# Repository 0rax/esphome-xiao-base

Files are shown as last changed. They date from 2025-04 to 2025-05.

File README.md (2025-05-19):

# XIAO Base for ESPHome





The XIAO Base for ESPHome is a custom PCB designed to be used with the [ESPHome](https://esphome.io/) firmware as a base for creating new sensors.

It was made as a carrier board for the XIAO series of microcontrollers with an OLED display and three switches while providing an easy-to-access header on the back for standard communication protocols (I²C, UART and SPI).

A cutout has also been left for the underside of the XIAO to allow access to the battery pads available on the underside of some modules (such as the [XIAO ESP32C6]).

## PCB

| Render | Front | Back |
| :---: | :---: | :---: |
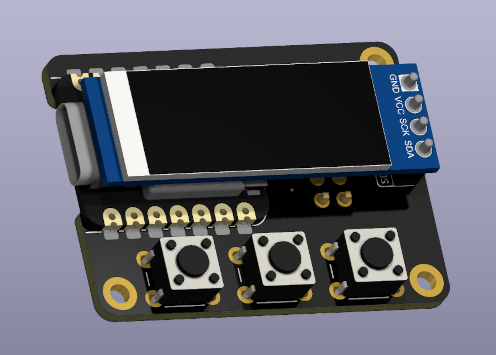
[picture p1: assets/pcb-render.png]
PCB Render
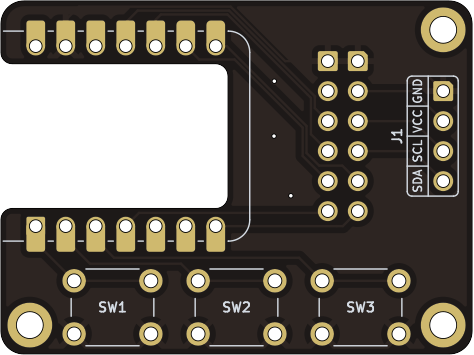
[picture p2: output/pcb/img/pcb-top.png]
PCB Front
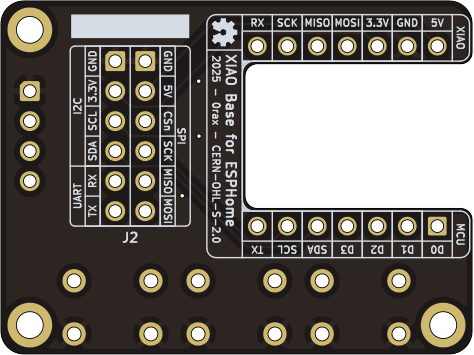
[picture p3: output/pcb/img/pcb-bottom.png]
PCB Back
| [][PCB Render] | [][PCB Front] | [][PCB Back] |

[PCB Render]: assets/pcb-render.png
[PCB Front]: output/pcb/img/pcb-top.png
[PCB Back]: output/pcb/img/pcb-bottom.png

The PCB has been designed in [KiCad EDA 9.0](https://www.kicad.org/).

You can preview the project files using [KiCanvas](https://kicanvas.org/?github=https%3A%2F%2Fgithub.com%2F0rax%2Fesphome-xiao-base%2Ftree%2Fmain%2Fpcb) directly in your browser, the exported schematic is also available under [`output/schematics`](output/schematics/).

### PCB Order

The necessary Gerber files to order the PCB are available in the [`output/fabrication/jlcpcb`](output/fabrication/jlcpcb) directory. They have been generated specifically for [JLCPCB](https://jlcpcb.com/) using [KiBot](https://kibot.readthedocs.io/). They should be compatible with other PCB manufacturers too.

Here is the list of parameters to use for the PCB order:

| Parameters | Value | Parameters | Value |
| --- | --- | --- | --- |
| **Base Material** | FR4 | **Copper Weight** | 1 oz |
| **Layers** | 2 | **Via Covering** | Tented |
| **Dimensions** | 40 × 30 mm | **Min Via Hole Size** | 0.3 mm |
| **PCB Thickness** | 1.2 or 1.6 mm | **Board Outline Tolerance** | ± 0.2 mm |
| **PCB Color** [^pcb-color] | Black | **Mark on PCB** [^jlcpcb-mark] | 2D Barcode (Serial Number) |
| **Silkscreen** | White | | > Printing: Number Only |
| **Surface Finish** [^surface-finish] | Lead Free HASL or ENIG | | > Position: Specify Position |

[^pcb-color]: You can select any PCB color you want but some manufacturers such as JLCPCB may charge you more for uncommon combos (such as Blue PCB + ENIG Surface Finish).
[^surface-finish]: The "HASL (with lead)" option is extremely discouraged due to the risk of lead poisoning. We strongly recommend paying the premium for the "Lead Free HASL" option.
[^jlcpcb-mark]: JLCPCB specific option, a pre-configured footprint has been added for a serial number to be printed on the back of the PCB.

### BOM

| Part | Ref. | Quantity | Remarks |
| --- | --- | :---: | --- |
| PCB | [XIAO Base for ESPHome PCB](./README.md#pcb) | 1 | See the previous section on how to order it. |
| XIAO Controller | [XIAO ESP32C3], [XIAO ESP32C6] or [XIAO ESP32S3] | 1 | Any ESPHome compatible XIAO controller should work. |
| Tactile Switch  | [SCHURTER 1301.9303] | 3 | Any 6 × 6 mm thru-hole tactile switch should work. We recommend a model with a stem length of 3 mm or more. |
| OLED Display | [SSD1306 0.91" OLED Display] or [SSD1107 0.96" OLED Display] | 1 | Any SSD1306 or SSD1106 I²C based display should work. The PCB was designed to accommodate both 0.91" (128 × 32) and 0.96" (64 × 128) modules. |

[SSD1306 0.91" OLED Display]: https://www.aliexpress.com/item/32777216785.html
[SSD1107 0.96" OLED Display]: https://aliexpress.com/item/1005005814186982.html
[XIAO ESP32C3]: https://www.seeedstudio.com/Seeed-XIAO-ESP32C3-p-5431.html
[XIAO ESP32C6]: https://www.seeedstudio.com/Seeed-Studio-XIAO-ESP32C6-p-5884.html
[XIAO ESP32S3]: https://www.seeedstudio.com/XIAO-ESP32S3-p-5627.html
[SCHURTER 1301.9303]: https://www.digikey.com/en/products/detail/schurter-inc/1301-9303/3189753

## ESPHome

Example ESPHome configuration files can be found in the [`esphome`](esphome/) directory.

Two are provided for the [XIAO ESP32C6] and [XIAO ESP32S3] with two different type of OLED display.
They should be easily modifiable to fit any ESPHome compatible XIAO microcontrollers and displays.

## Add-ons

### AQStation

| Front | Back |
| :---: | :---: |
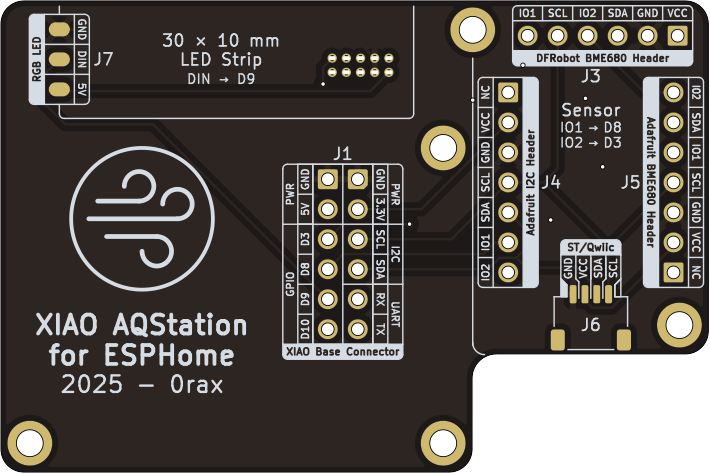
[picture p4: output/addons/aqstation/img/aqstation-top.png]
AQStation Front
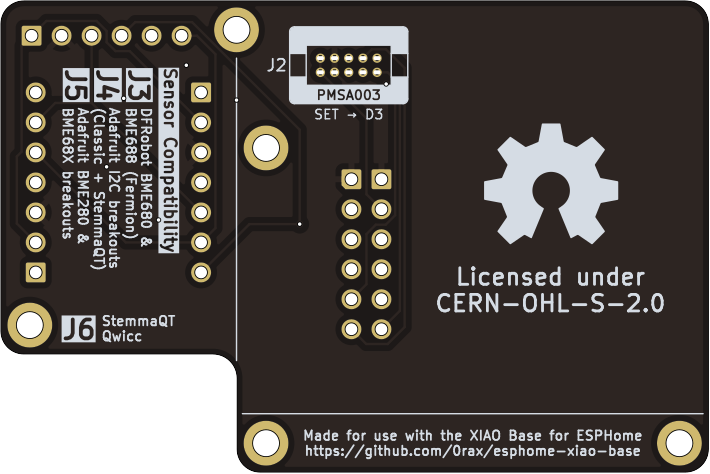
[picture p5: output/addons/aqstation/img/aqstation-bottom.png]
AQStation Back
| [][AQStation Front] | [][AQStation Back] |

[AQStation Front]: output/addons/aqstation/img/aqstation-top.png
[AQStation Back]: output/addons/aqstation/img/aqstation-bottom.png

An indoor air quality station fit to accept a [Plantower PMSA003](https://plantower.com/en/products_33/77.html) particulate matter sensor and a [Bosch BME688](https://www.bosch-sensortec.com/products/environmental-sensors/gas-sensors/bme688/) gas, temperature, humidity and pressure sensor.

In order to support as many breakouts as possible, the PCB was designed to be modular with 3 different headers. Here is a list of what should be compatible with the PCB:

- Adafruit BME680 Header
  - [Adafruit BME280](https://www.adafruit.com/product/2652)
  - [Adafruit BME680](https://www.adafruit.com/product/3660)
  - [Adafruit BME688](https://www.adafruit.com/product/5046)
- Adafruit I2C Header
  - [BME680 Purple Breakout](https://www.studiopieters.nl/bme680-gas-sensor/)
  - A lot of other sensor breakouts share compatible pinouts that are not from the BME680 family such as:
    - [Adafruit Si7021](https://www.adafruit.com/product/3251)
    - [Adafruit MCP9808](https://www.adafruit.com/product/1782)
    - [Adafruit AHT20](https://www.adafruit.com/product/4566)
    - [DFRobot Fermion SHT40](https://www.dfrobot.com/product-2437.html)
    - [DFRobot Fermion SHT31](https://www.dfrobot.com/product-2013.html)
    - [DFRobot Fermion SHTC3](https://www.dfrobot.com/product-2436.html)
    - [DFRobot Fermion AHT20](https://www.dfrobot.com/product-2603.html)
    - [DFRobot Fermion SHT35](https://www.dfrobot.com/product-2016.html)
- DFRobot BME680 Header
  - [DFRobot Fermion BME680](https://www.dfrobot.com/product-2143.html)
  - [DFRobot Fermion BME688](https://www.dfrobot.com/product-2918.html)

The PCB also includes a STEMMA QT / Qwiic connector to further expand the capabilities of the device, this header is compatible with the following ecosystems:

- [Adafruit STEMMA QT](https://learn.adafruit.com/introducing-adafruit-stemma-qt/what-is-stemma-qt)
- [SparkFun Qwiic](https://www.sparkfun.com/qwiic)
- [Soldered easyC](https://soldered.com/easyC/)

### SensorBoard

| Front | Back |
| :---: | :---: |
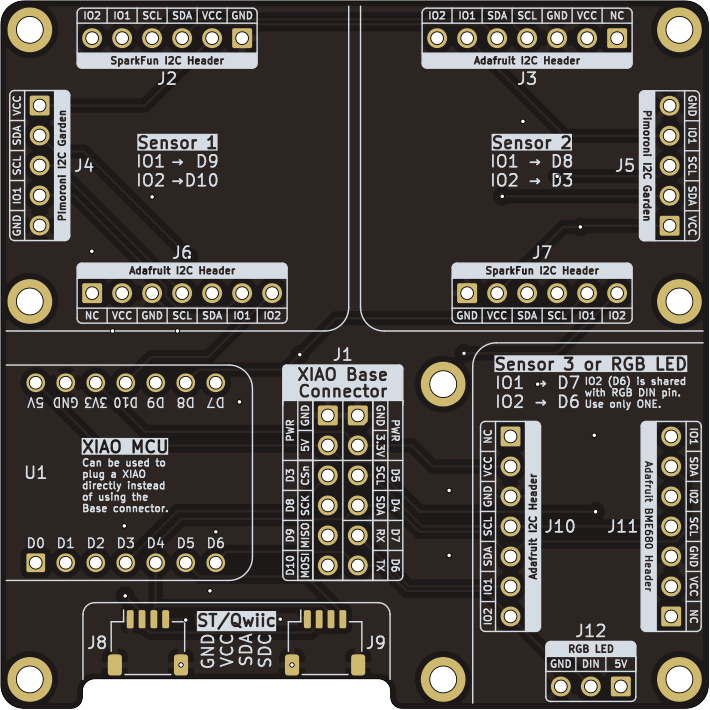
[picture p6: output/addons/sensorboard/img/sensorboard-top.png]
SensorBoard Front
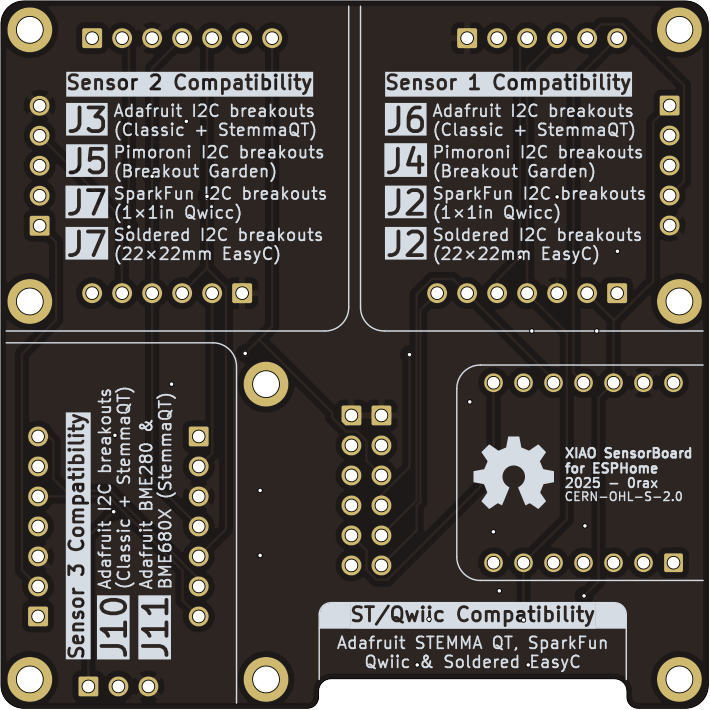
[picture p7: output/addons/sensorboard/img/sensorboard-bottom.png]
SensorBoard Back
| [][SensorBoard Front] | [][SensorBoard Back] |

[SensorBoard Front]: output/addons/sensorboard/img/sensorboard-top.png
[SensorBoard Back]: output/addons/sensorboard/img/sensorboard-bottom.png

A development board to test and develop ESPHome configurations using various breakout boards and sensors.

It was designed to accept up to 3 sensors on the board using different headers and has 2 STEMMA QT / Qwiic connectors to expand it even further. This board can either be used as an add-on for the XIAO Base or as a standalone board by plugging a XIAO MCU directly.

The different headers / connectors are:

- Sensor 1
  - Adafruit I2C Header
  - SparkFun I2C Header
  - Pimoroni I2C Garden
- Sensor 2
  - Adafruit I2C Header
  - SparkFun I2C Header
  - Pimoroni I2C Garden
- Sensor 3
  - Adafruit I2C Header
  - Adafruit BME680 Header
  - RGB LED header
- 2× STEMMA QT / Qwiic connectors

Make sure to check out the pinouts and notes on the PCB for more information on which pins are used for what as well as the back of the PCB for more information on header compatibility.
A more complete compatibility list can be found in the schematic files.

## Notes

### Potential Modifications

- The XIAO microcontroller is currently soldered at the front of the PCB making the OLED display require a double stacked header for clearance as well as force the use of switches with extended stem. Moving it to the back of the PCB would allow for everything in the front to be made smaller but would make access to the battery pads on the back of the XIAO and the `RST` / `BOOTSEL` buttons more difficult.
- Adding some sort of STEMMA QT / Qwiic connector to the back of the PCB would make it easier to integration some sensors though space is quite limited.

## License

This design is licensed under the [CERN Open Hardware Licence Version 2 – Strongly Reciprocal (CERN-OHL-S-2.0)](https://opensource.org/license/cern-ohl-s).

You are free to use, modify, and distribute this design for any purpose, provided that:

- **Attribution**: Appropriate credit is given, a link to the license is provided, and any modifications are clearly indicated.
- **Reciprocity**: Any derivative works must be released under the same license.

If you are a retailer or business interested in producing or selling this design or related products, I’d love to discuss it! Please feel free to reach out, so we can explore potential arrangements.

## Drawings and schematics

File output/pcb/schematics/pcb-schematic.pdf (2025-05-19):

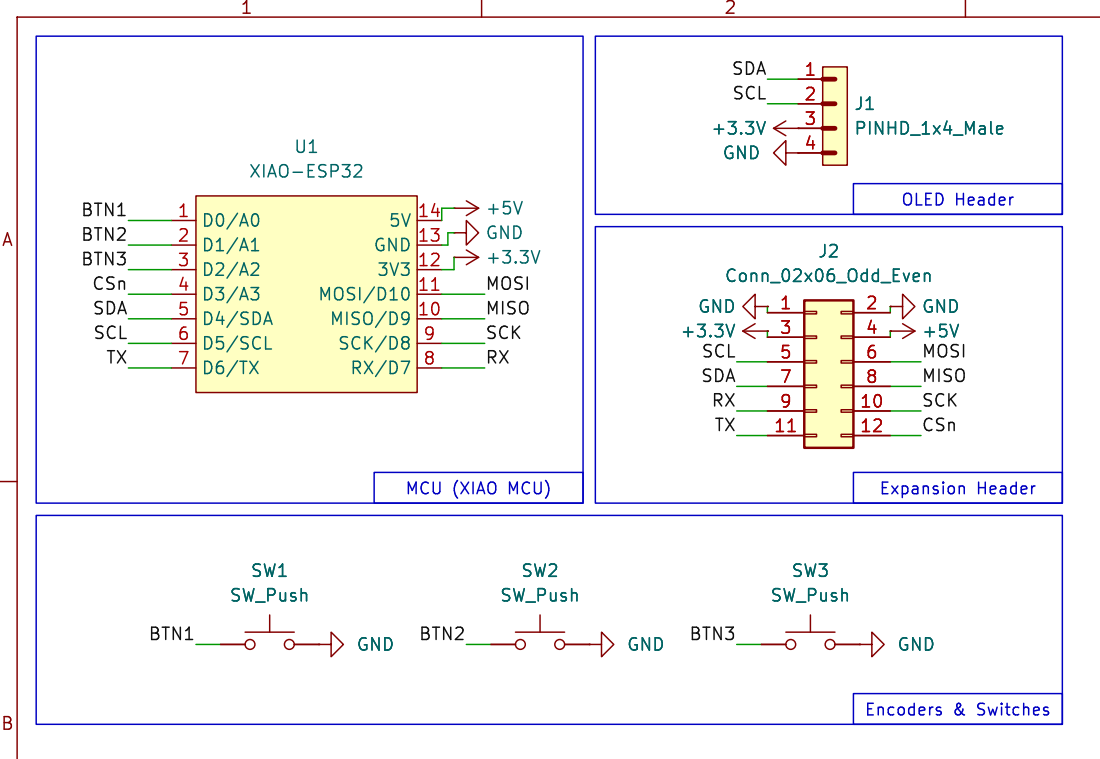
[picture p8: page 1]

https://github.com/0rax/esphome-xiao-base/
File: pcb.kicad_sch Sheet: / 0rax

Id: 1/1 Title: XIAO Base for ESPHome

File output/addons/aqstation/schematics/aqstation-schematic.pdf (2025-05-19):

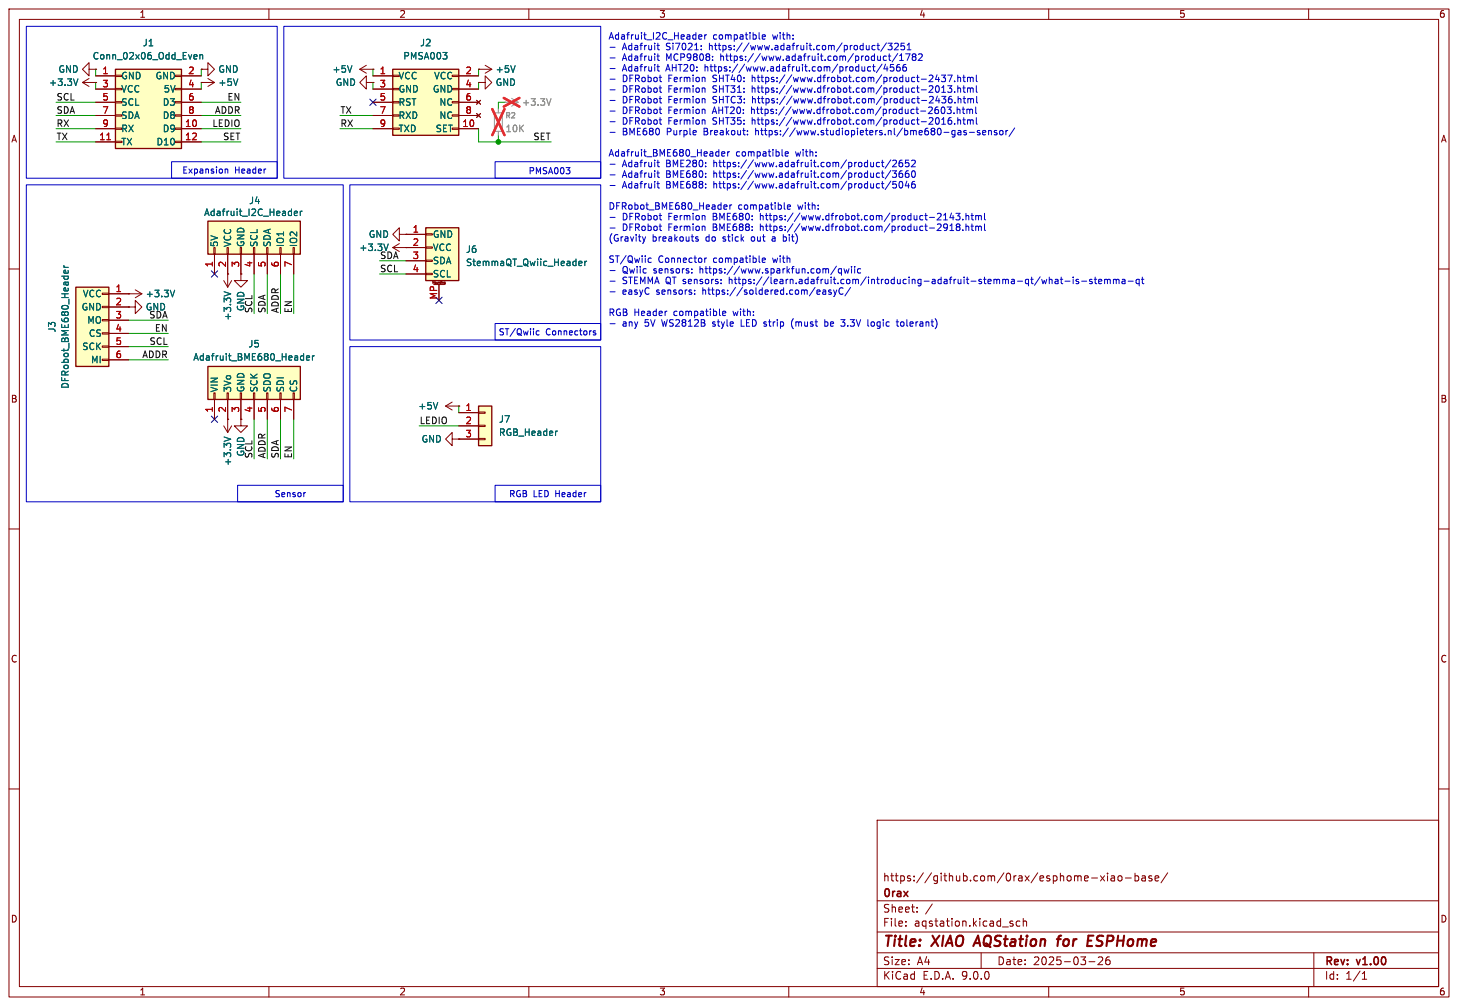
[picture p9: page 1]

- Adafruit MCP9808: https://www.adafruit.com/product/1782
- Adafruit AHT20: https://www.adafruit.com/product/4566

- Adafruit BME680: https://www.adafruit.com/product/3660

7 GND J3 DFRobot_BME680_Header VCC 1 GND 2 MO 3 CS 4 SCK 5 MI 6

- Qwiic sensors: https://www.sparkfun.com/qwiic

https://github.com/0rax/esphome-xiao-base/ +3.3V

Id: 1/1 Title: XIAO AQStation for ESPHome

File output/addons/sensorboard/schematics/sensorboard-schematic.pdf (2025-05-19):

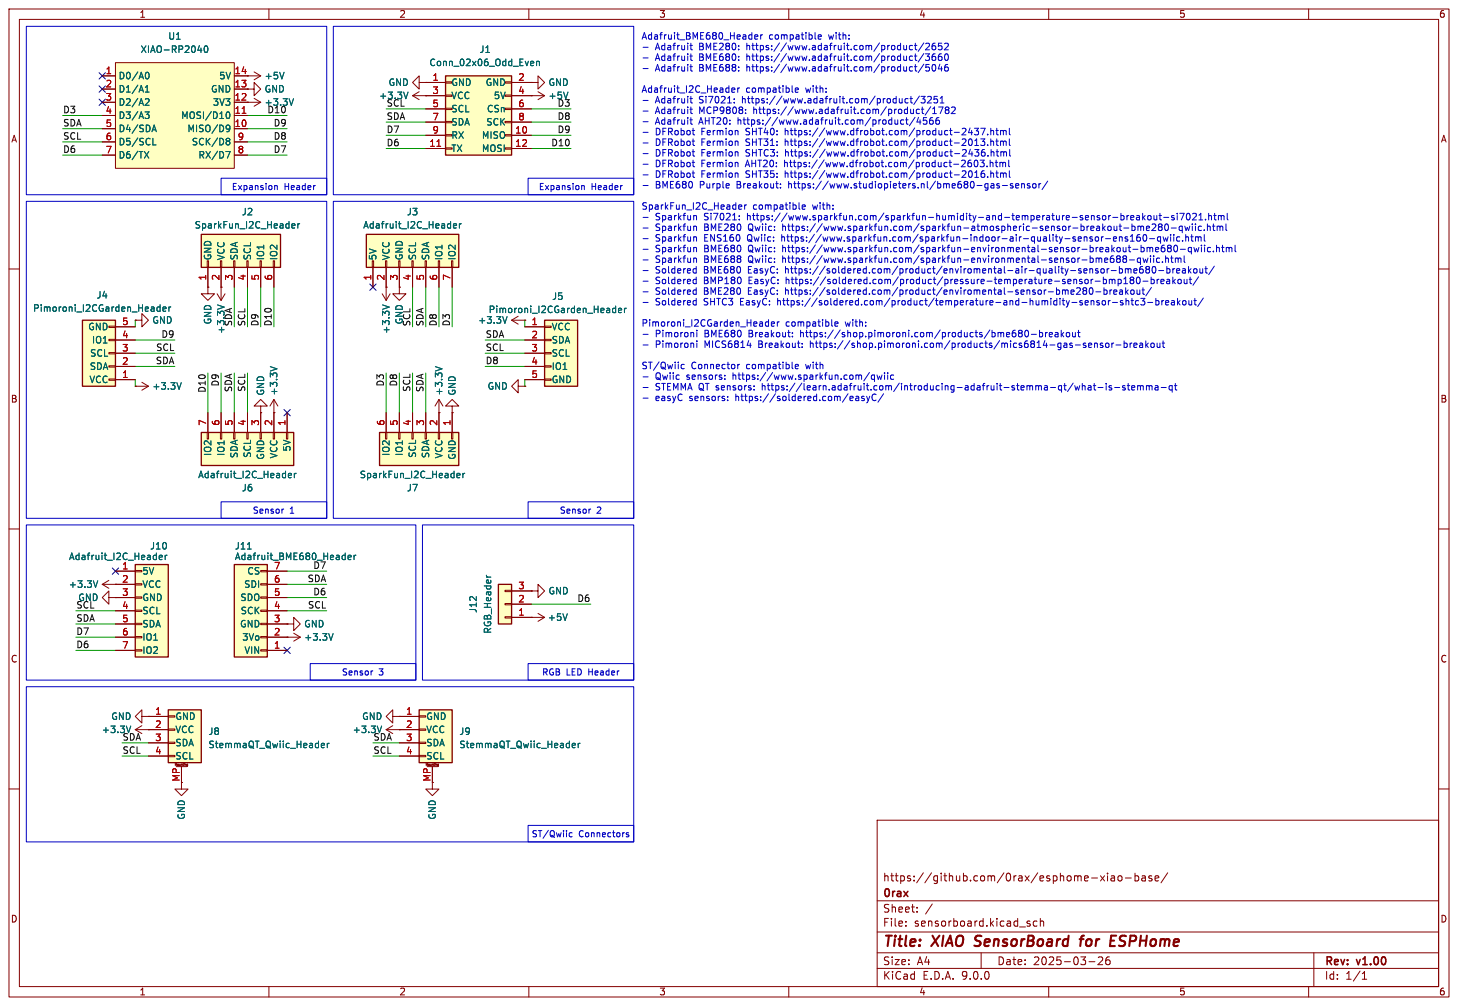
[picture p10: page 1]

+3.3V U1 XIAO-RP2040 D0/A0 1 D1/A1 2 D2/A2 3 D3/A3 4 D4/SDA 5 D5/SCL 6 D6/TX 7

- Adafruit BME680: https://www.adafruit.com/product/3660

- Adafruit MCP9808: https://www.adafruit.com/product/1782
- Adafruit AHT20: https://www.adafruit.com/product/4566

- Qwiic sensors: https://www.sparkfun.com/qwiic

- STEMMA QT sensors: https://learn.adafruit.com/introducing-adafruit-stemma-qt/what-is-stemma-qt - easyC sensors: https://soldered.com/easyC/ Sensor 2 Sensor 3

https://github.com/0rax/esphome-xiao-base/
File: sensorboard.kicad_sch Sheet: / 0rax

Id: 1/1 Title: XIAO SensorBoard for ESPHome

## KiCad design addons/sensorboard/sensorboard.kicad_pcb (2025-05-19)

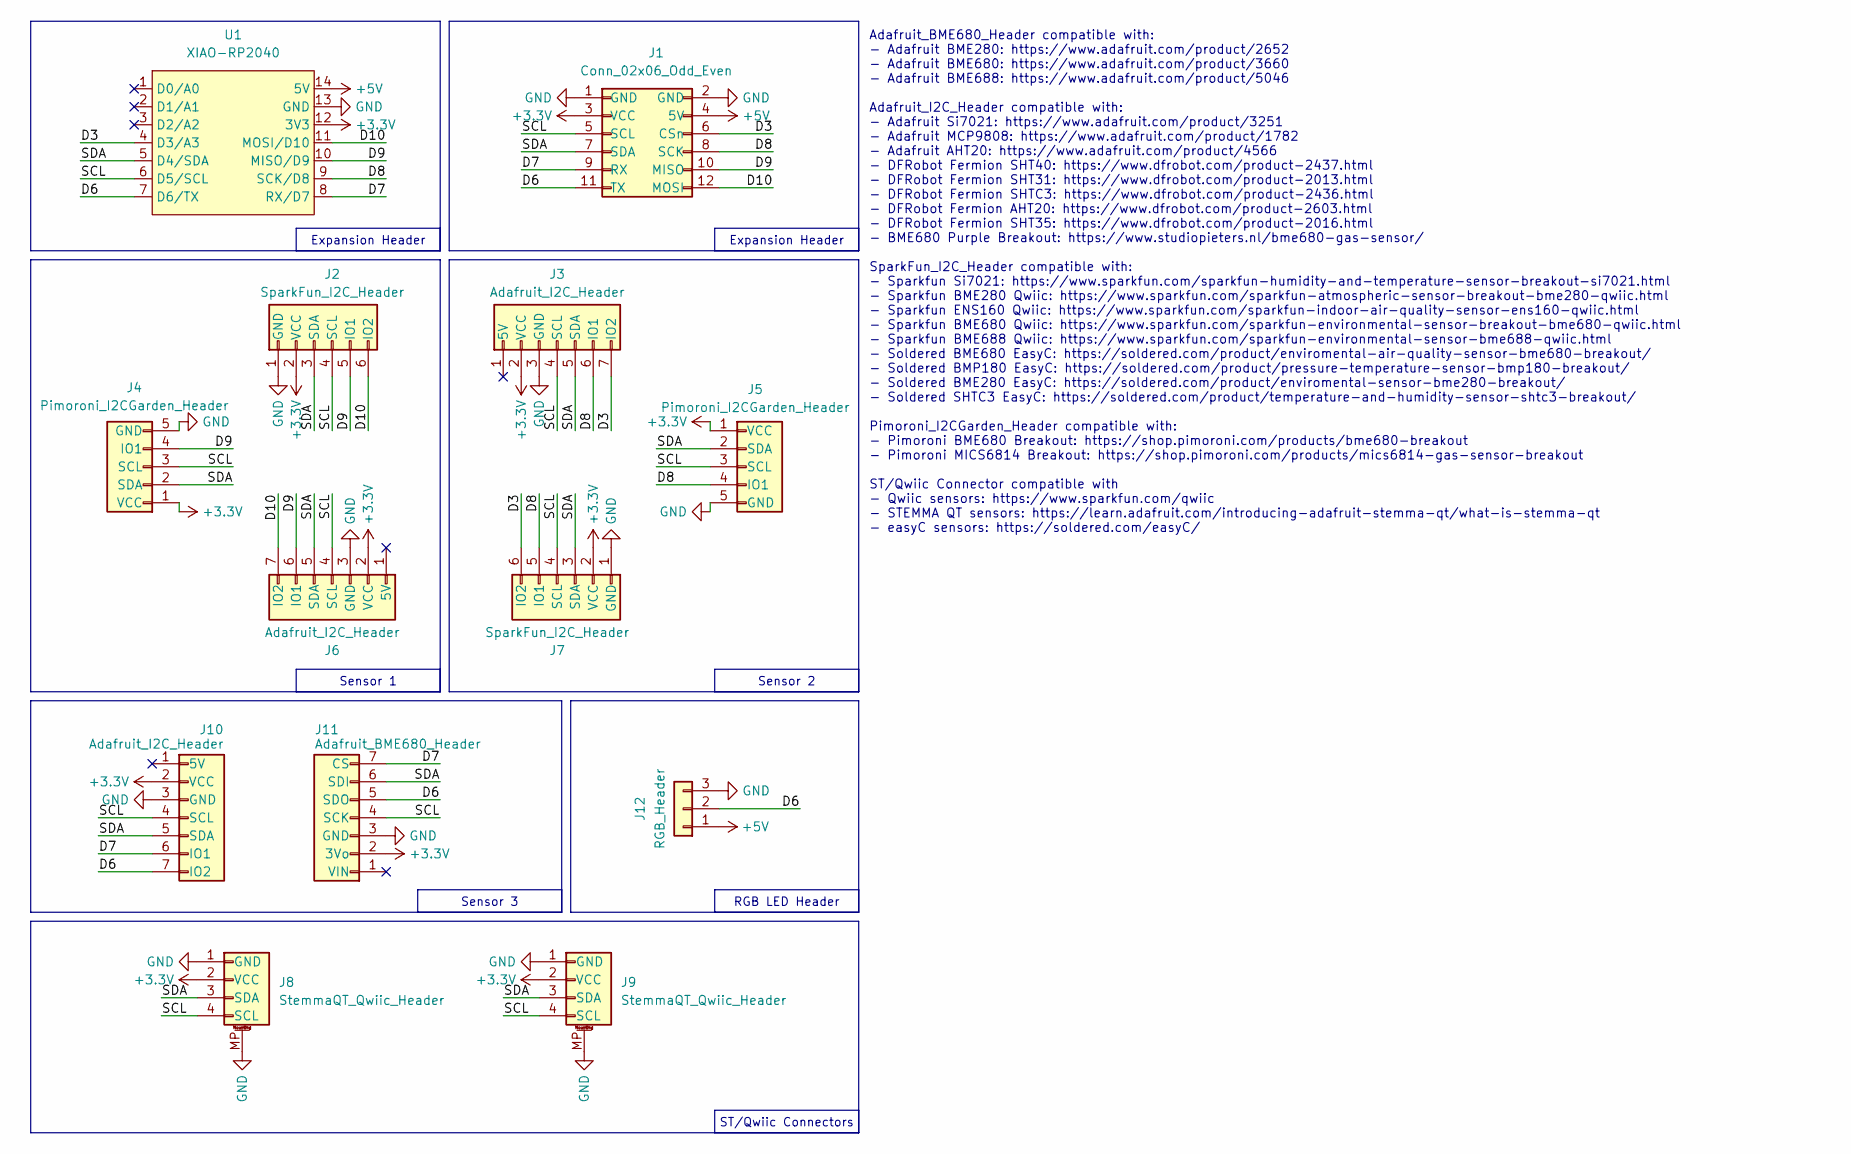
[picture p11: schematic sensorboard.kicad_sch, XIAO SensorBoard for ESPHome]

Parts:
J1: Conn_02x06_Odd_Even; XIAOBase_Header
J2, J7: SparkFun_I2C_Header
J3, J6, J10: Adafruit_I2C_Header
J4, J5: Pimoroni_I2CGarden_Header
J8, J9: StemmaQT_Qwiic_Header; JST_SH_SM04B-SRSS-TB_1x04-1MP_P1.00mm_Horizontal
J11: Adafruit_BME680_Header
J12: RGB_Header; NeoPixel_Header
U1: XIAO-RP2040; MCU_XIAO-RP2040

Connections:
+3.3V: J1.3 (VCC), J2.2 (VCC), J3.2 (VCC), J4.1 (VCC), J5.1 (VCC), J6.2 (VCC), J7.2 (VCC), J8.2 (VCC), J9.2 (VCC), J10.2 (VCC), J11.2 (3Vo), U1.12 (3V3)
+5V: J1.4 (5V), J12.1, U1.14 (5V)
/D3: J1.6 (CSn), J3.7 (IO2), J7.6 (IO2), U1.4 (D3/A3)
/D6: J1.11 (TX), J10.7 (IO2), J11.5 (SDO), J12.2, U1.7 (D6/TX)
/D7: J1.9 (RX), J10.6 (IO1), J11.7 (CS), U1.8 (RX/D7)
/D8: J1.8 (SCK), J3.6 (IO1), J5.4 (IO1), J7.5 (IO1), U1.9 (SCK/D8)
/D9: J1.10 (MISO), J2.5 (IO1), J4.4 (IO1), J6.6 (IO1), U1.10 (MISO/D9)
/D10: J1.12 (MOSI), J2.6 (IO2), J6.7 (IO2), U1.11 (MOSI/D10)
/SCL: J1.5 (SCL), J2.4 (SCL), J3.4 (SCL), J4.3 (SCL), J5.3 (SCL), J6.4 (SCL), J7.4 (SCL), J8.4 (SCL), J9.4 (SCL), J10.4 (SCL), J11.4 (SCK), U1.6 (D5/SCL)
/SDA: J1.7 (SDA), J2.3 (SDA), J3.5 (SDA), J4.2 (SDA), J5.2 (SDA), J6.5 (SDA), J7.3 (SDA), J8.3 (SDA), J9.3 (SDA), J10.5 (SDA), J11.6 (SDI), U1.5 (D4/SDA)
GND: J1.1 (GND), J1.2 (GND), J2.1 (GND), J3.3 (GND), J4.5 (GND), J5.5 (GND), J6.3 (GND), J7.1 (GND), J8.1 (GND), J8.MP (MountPin), J9.1 (GND), J9.MP (MountPin), J10.3 (GND), J11.3 (GND), J12.3, U1.13 (GND)

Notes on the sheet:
Expansion Header
RGB LED Header
Sensor 1
ST/Qwiic Connectors
Adafruit_BME680_Header compatible with: - Adafruit BME280: https://www.adafruit.com/product/2652 - Adafruit BME680: https://www.adafruit.com/product/3660 - Adafruit BME688: https://www.adafruit.com/product/5046 Adafruit_I2C_Header compatible with: - Adafruit Si7021: https://www.adafruit.com/product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
Sensor 3
Sensor 2

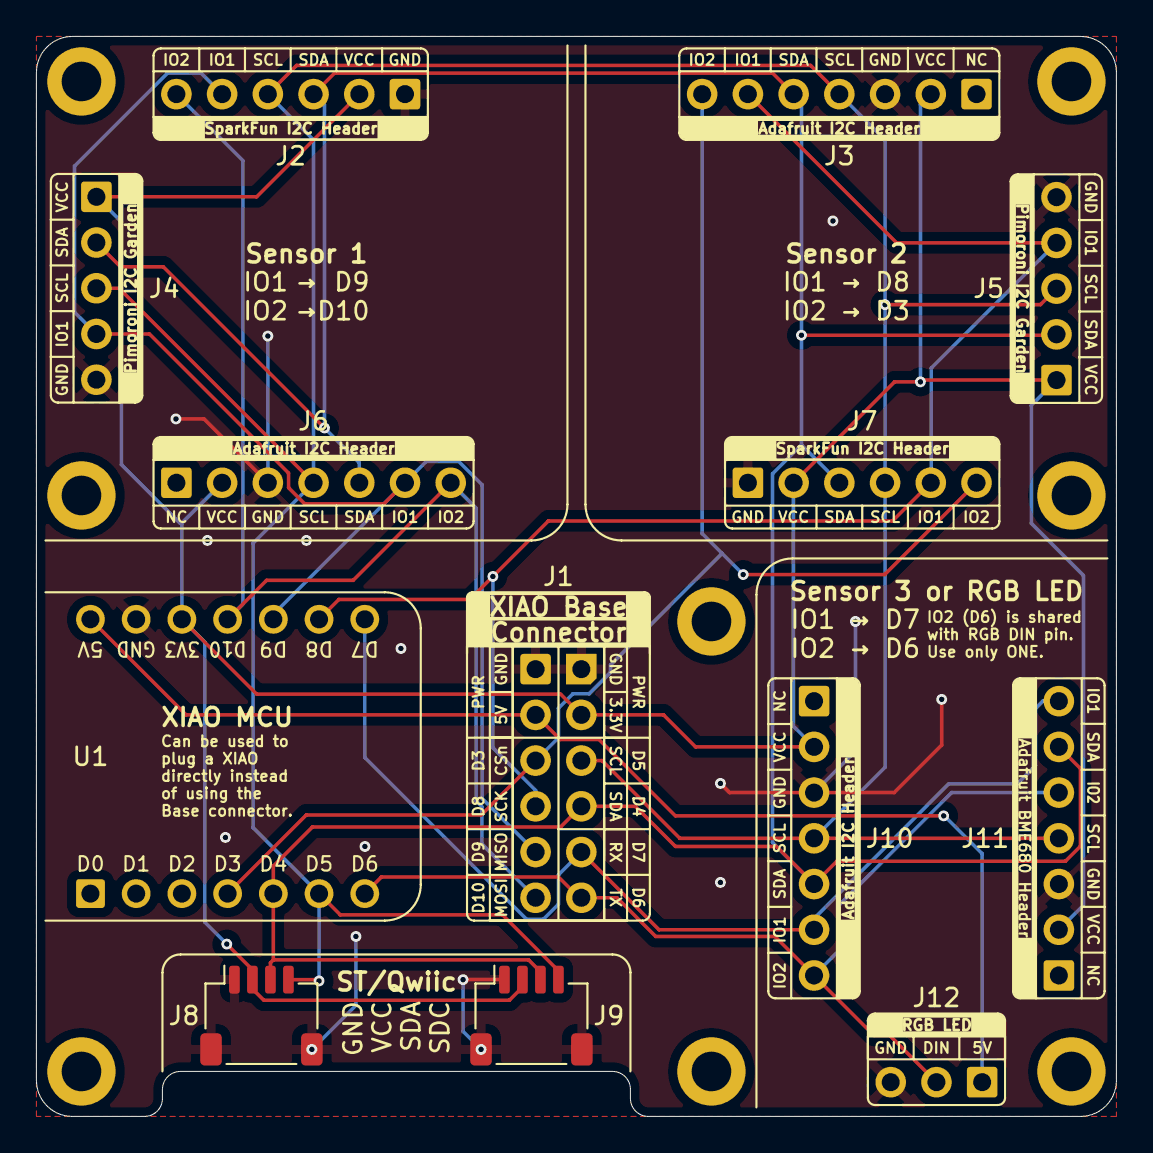
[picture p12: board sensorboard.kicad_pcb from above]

Board: 2 copper layers, 60.0 x 60.0 mm, 21 parts (0 on the bottom side), 11 nets.

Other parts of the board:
H1, H3, H4, H5, H7, H8, H9, H10: MountingHole_2.2mm_M2_ISO14580_Pad

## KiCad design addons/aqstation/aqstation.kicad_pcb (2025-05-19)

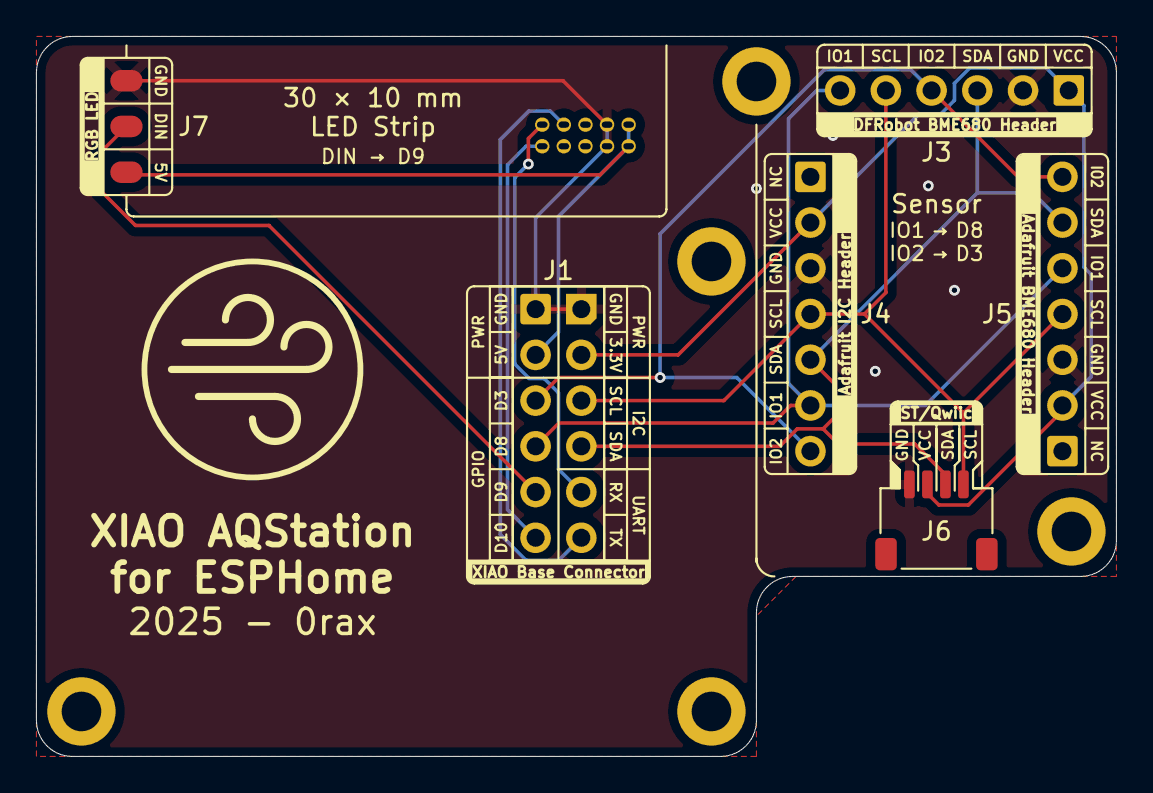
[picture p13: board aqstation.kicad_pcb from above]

Board: 2 copper layers, 60.0 x 40.0 mm, 12 parts (1 on the bottom side), 11 nets.

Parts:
H1, H3, H4, H5, H6: MountingHole_2.2mm_M2_ISO14580_Pad
J1: Conn_02x06_Odd_Even; XIAOBase_Header
J2: PMSA003
J3: DFRobot_BME680_Header
J4: Adafruit_I2C_Header
J5: Adafruit_BME680_Header
J6: StemmaQT_Qwiic_Header; JST_SH_SM04B-SRSS-TB_1x04-1MP_P1.00mm_Horizontal
J7: RGB_Header; NeoPixel_Header

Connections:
+3.3V: J1.3 (VCC), J3.1 (VCC), J4.2 (VCC), J5.2 (3Vo), J6.2 (VCC)
+5V: J1.4 (5V), J2.1 (VCC), J2.2 (VCC), J7.1
/ADDR: J1.8 (D8), J3.6 (MI), J4.6 (IO1), J5.5 (SDO)
/EN: J1.6 (D3), J3.4 (CS), J4.7 (IO2), J5.7 (CS)
/LEDIO: J1.10 (D9), J7.2
/RX: J1.9 (RX), J2.9 (TXD)
/SCL: J1.5 (SCL), J3.5 (SCK), J4.4 (SCL), J5.4 (SCK), J6.4 (SCL)
/SDA: J1.7 (SDA), J3.3 (MO), J4.5 (SDA), J5.6 (SDI), J6.3 (SDA)
/SET: J1.12 (D10), J2.10 (SET)
/TX: J1.11 (TX), J2.7 (RXD)
GND: J1.1 (GND), J1.2 (GND), J2.3 (GND), J2.4 (GND), J3.2 (GND), J4.3 (GND), J5.3 (GND), J6.1 (GND), J7.3

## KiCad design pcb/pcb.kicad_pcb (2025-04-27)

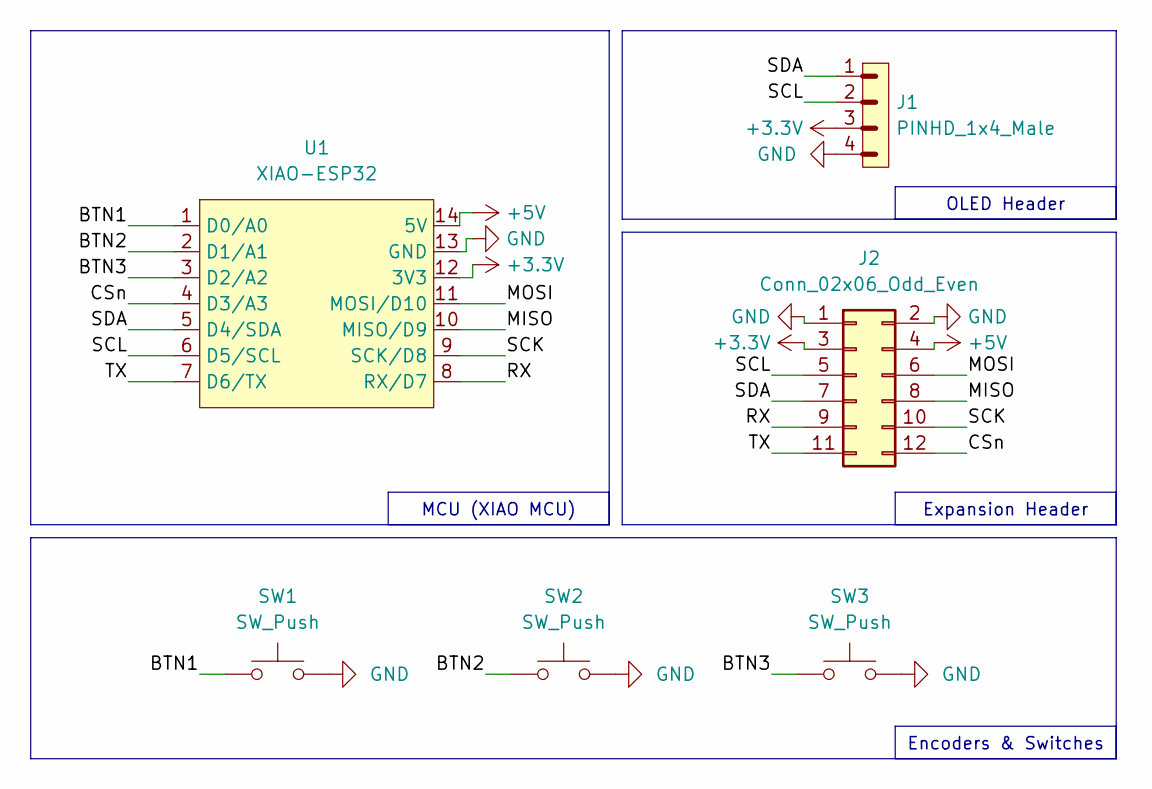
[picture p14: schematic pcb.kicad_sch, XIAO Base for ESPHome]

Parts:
J1: PINHD_1x4_Male; OLED_SSD1306_128x32_0.91inch_I2C
J2: Conn_02x06_Odd_Even; PinHeader_2x06_P2.54mm_Vertical
SW1, SW2, SW3: SW_Push; SW_PUSH_6mm
U1: XIAO-ESP32; MCU_XIAO-RP2040

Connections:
+3.3V: J1.3, J2.3, U1.12 (3V3)
+5V: J2.4, U1.14 (5V)
/BTN1: SW1.1, U1.1 (D0/A0)
/BTN2: SW2.1, U1.2 (D1/A1)
/BTN3: SW3.1, U1.3 (D2/A2)
/CSn: J2.12, U1.4 (D3/A3)
/MISO: J2.8, U1.10 (MISO/D9)
/MOSI: J2.6, U1.11 (MOSI/D10)
/RX: J2.9, U1.8 (RX/D7)
/SCK: J2.10, U1.9 (SCK/D8)
/SCL: J1.2, J2.5, U1.6 (D5/SCL)
/SDA: J1.1, J2.7, U1.5 (D4/SDA)
/TX: J2.11, U1.7 (D6/TX)
GND: J1.4, J2.1, J2.2, SW1.2, SW2.2, SW3.2, U1.13 (GND)

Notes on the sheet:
Expansion Header
MCU (XIAO MCU)
OLED Header
Encoders & Switches

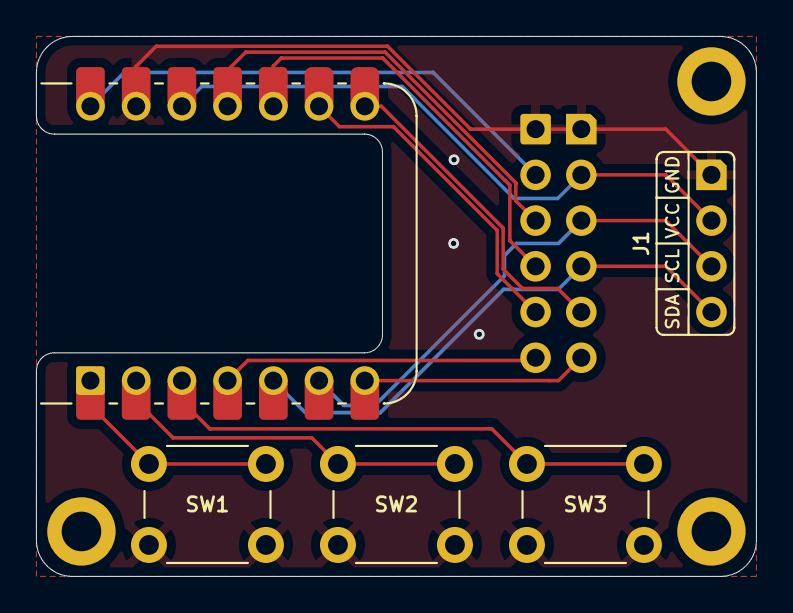
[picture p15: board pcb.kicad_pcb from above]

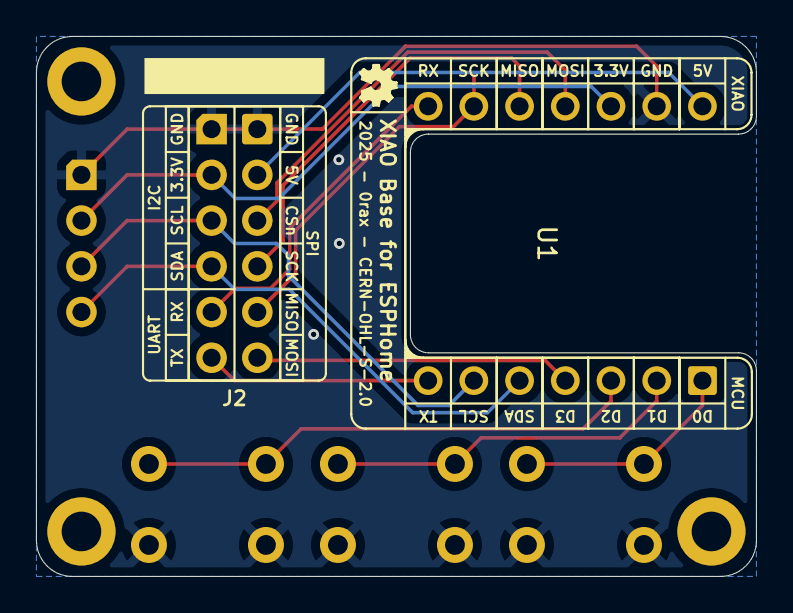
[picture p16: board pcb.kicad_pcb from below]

Board: 2 copper layers, 40.0 x 30.0 mm, 10 parts (2 on the bottom side), 14 nets.

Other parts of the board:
H1, H2, H3: MountingHole_2.2mm_M2_ISO14580_Pad
REF1: JLCPCB_SerialNumber_2x10mm

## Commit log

2025-03-26 Initial PCB design
    [pcb-3D.step, pcb.kicad_pcb, pcb.kicad_sch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]
2025-04-09 Add example ESPHome configurations
    [pcb-3D.step]
2025-04-09 Add PCB render
2025-04-09 Update Schematics and PCB properties
    [pcb-3D.step, pcb.kicad_pcb, pcb.kicad_sch]
2025-04-27 Add AQStation & SensorBoard addons
    [aqstation.kicad_pcb, aqstation.kicad_sch, pcb-3D.step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]
2025-04-29 More compact version of the AQStation
    [aqstation.kicad_pcb, aqstation.kicad_sch, sensorboard.kicad_pcb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]
2025-04-29 Switch LED header to just some pads
    [aqstation.kicad_pcb]
2025-04-29 Remove solderpaste from pcbdraw export
    [aqstation.kicad_pcb]
2025-04-29 Cleanup wiring
    [aqstation.kicad_pcb]
2025-05-05 Finalize aqstation
    [aqstation.kicad_pcb, aqstation.kicad_sch, sensorboard.kicad_pcb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]
2025-05-19 Fix issues with the initial version and add support for DFRobot BME breakouts
    Update documentation
    [aqstation.kicad_pcb, aqstation.kicad_sch, sensorboard.kicad_pcb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]

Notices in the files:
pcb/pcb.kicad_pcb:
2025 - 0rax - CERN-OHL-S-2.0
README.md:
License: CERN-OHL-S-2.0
